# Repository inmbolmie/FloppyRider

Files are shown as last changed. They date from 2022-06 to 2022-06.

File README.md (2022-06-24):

# FloppyRider
Disk interface adapter to connect an IBM 31SD or 51TD 8-inch disk unit to a standard PC floppy controller

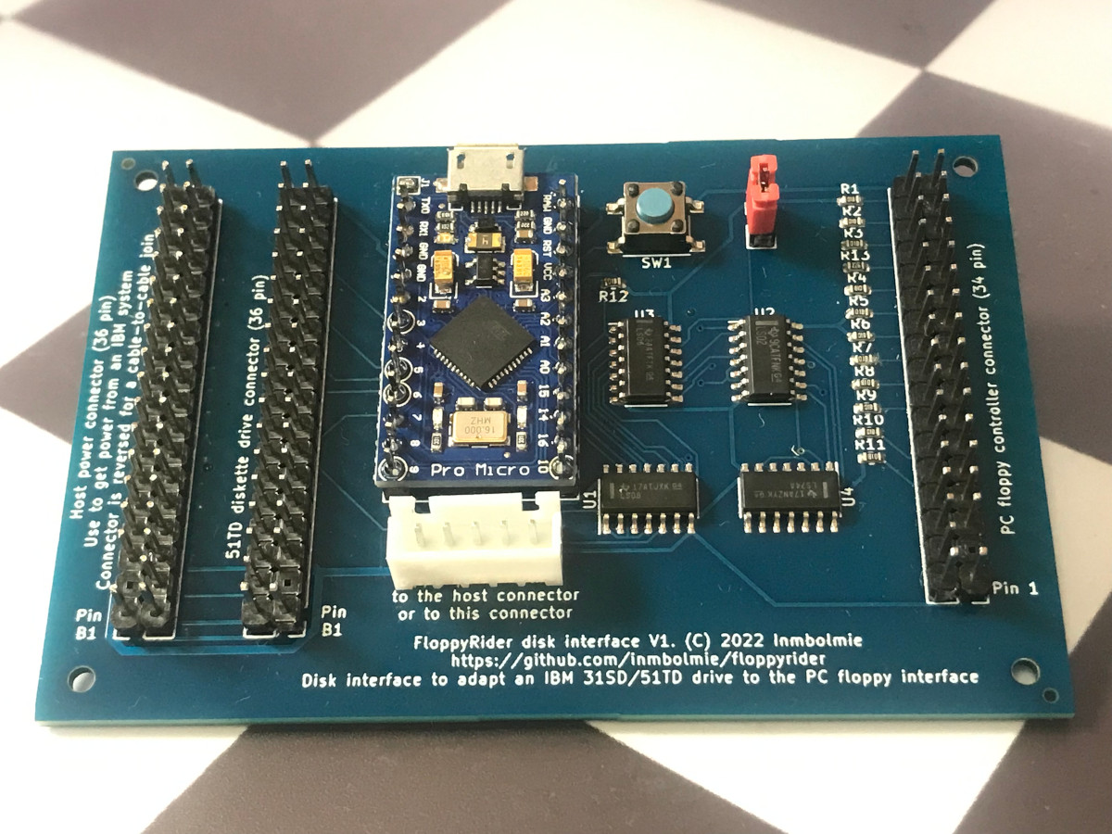
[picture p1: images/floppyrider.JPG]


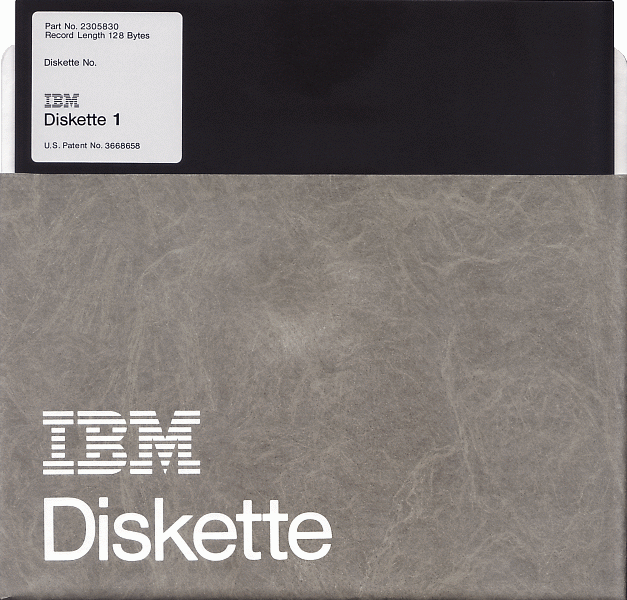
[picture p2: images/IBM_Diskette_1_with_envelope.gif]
Diskette


__This project is currently in Beta stage.__

__Second revision (20220624): I have added a transistor to drive the write/erase-gate signals on the IBM drive. I have noticed that write/erase-gate have a very low input impedance (90 ohms each, could that be a safety measure to make harder to accidentally drive the signal high?) that is way over-spec for the 74LS logic to drive properly. The prototype worked by pure luck but trying with other 74LS components the signal level was too low to enable the gates so the device was only capable of reading. The solution is to include a transistor to drive that signals up to aceptable levels.__

## Introduction

This is an ongoing project to create an adapter to be able to use IBM 8-inch Diskette drives with a standard PC floppy controller.

I currently have a working prototype capable of reading, writing and formatting Diskette 1,2 (SD) and 2D (DD) types on a 51TD disk drive. Further testing will be needed to consider it stable and fully operational.

## Videos

Video showing the adapter in action, here it is used to make an 8-inch diskette MSDOS-bootable:

[Booting MSDOS from an IBM 51TD 8-inch drive](https://www.youtube.com/watch?v=TbLUqG_d6FU)

Using the adapter to image a 33FD-formatted diskette with Imagedisk:

[Imaging on a PC an IBM 8-inch diskette with a 51TD diskette drive, Imagedisk and FloppyRider](https://www.youtube.com/watch?v=4pZ3qMAHVGs)

This project was inspired by CuriousMarc's video about data recovery from 8-inch floppies. This kind of converter is something Master Ken would have made like in five minutes using a Teensy, in case they wanted to use a genuine IBM Diskette drive in their data recovery adventure.

[Fossil Data Part 2: 8-Inch IBM Floppy Data Recovery](https://www.youtube.com/watch?v=5FVwheTVWko)

## Hardware

The adapter hardware is pretty straightforward and can be made cheapily with very low-cost components:

* Pin headers and IDC ribbon cables
* Arduino ProMicro microcontroller board (5V)
* 74LS02
* 74LS06
* 74LS08
* 74LS74
* 12x1K resistors
* 1x4,7K resistor
* NPN transistor

## Software

You can get the Arduino source code for the ProMicro in the __FloppyRider__ directory. You can program it using the regular Arduino IDE.

## KiCad Project

You can get the current project files in the __KiCad__ directory. The PCB design has not been validated at this point.

## Warning about some floppy controllers

It seems that some floppy controllers may ground the signals to the floppy drive when the computer is switched off. If you have a diskettte inserted and engaged when this happens, that can lead to the track where the head is currently positioned to be erased.

If you are working with important media be careful about this, and give power to the 51TD drive only __after__ the computer is switched on, and remove the diskette or the power to the disk drive __before__ the computer is switched off.

## Operation

These are the main points that need to be carried out for conversion:

#### Logic levels

The PC floppy signals are open collector low-level active, while the IBM signals are push-pull high-active. The 74 series chips provide most of the conversion.

All the signals are gated by the "drive select" PC signal for the adapter to be able to operate with another floppy drive on the same cable.

#### Track addressing

The PC floppy adresses tracks by a "direction" and "step" signal, and gets a "track 0" signal when the head is placed at such track. The IBM interface lacks a "track 0" signal and you control direcly the stepper motor signals "access 0" and "access 1". The ProMicro initializes the head position at track 0 at startup. From there it gets track of where the head is actually positioned and translates the required signals on both sides.

#### Write data signal.

The PC floppy write data signal generates a full pulse (falling and rising edge) for each magnetic flux transition that needs to be recorded on the disk surface, while in the IBM interface the "write data" signal records a magnetic flux transition for each signal level change (rising or falling edge). The conversion is made via the 74LS74 flip-flop.

## Connection

The 31SD and 51TD disk drives have pretty hefty power requirements, as you will need to provide them with:

* AC mains power for the disk rotating motor (on a separate connector)
* +24V at 12W (on the 36-pin idc connector)
* +5V (on the 36-pin idc connector)
* -5V (on the 36-pin idc connector)

The easier way to get all the required power rails is getting them from the original host hardware where the disk drive is enclosed. For that reason a 36-pin host connector header is provided. Note that the connector sides are mirrored to be able to use it with a cable-to-cable connection. The adapter will be placed as a bridge between the host cable and the disk drive header.

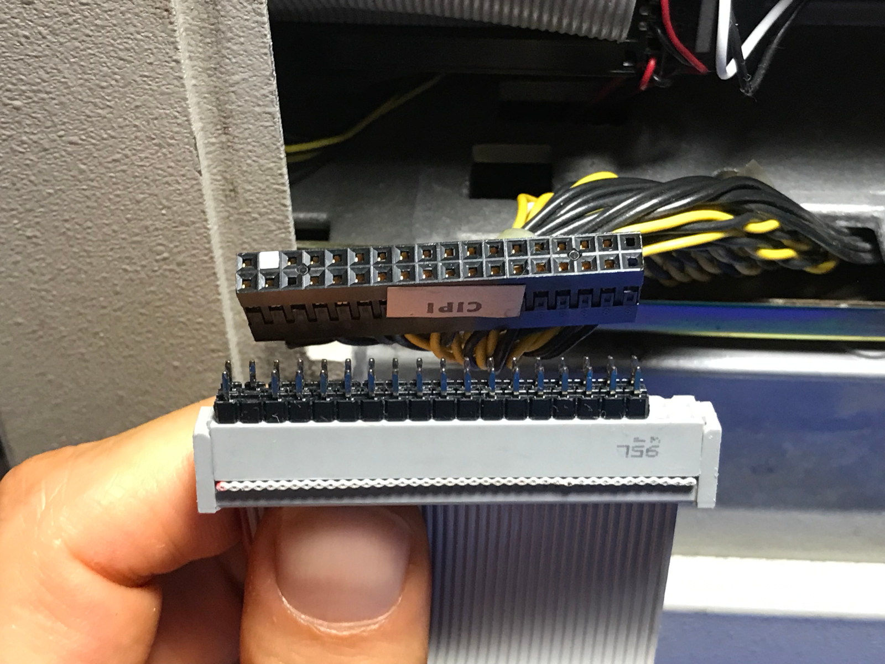
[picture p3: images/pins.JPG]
pins


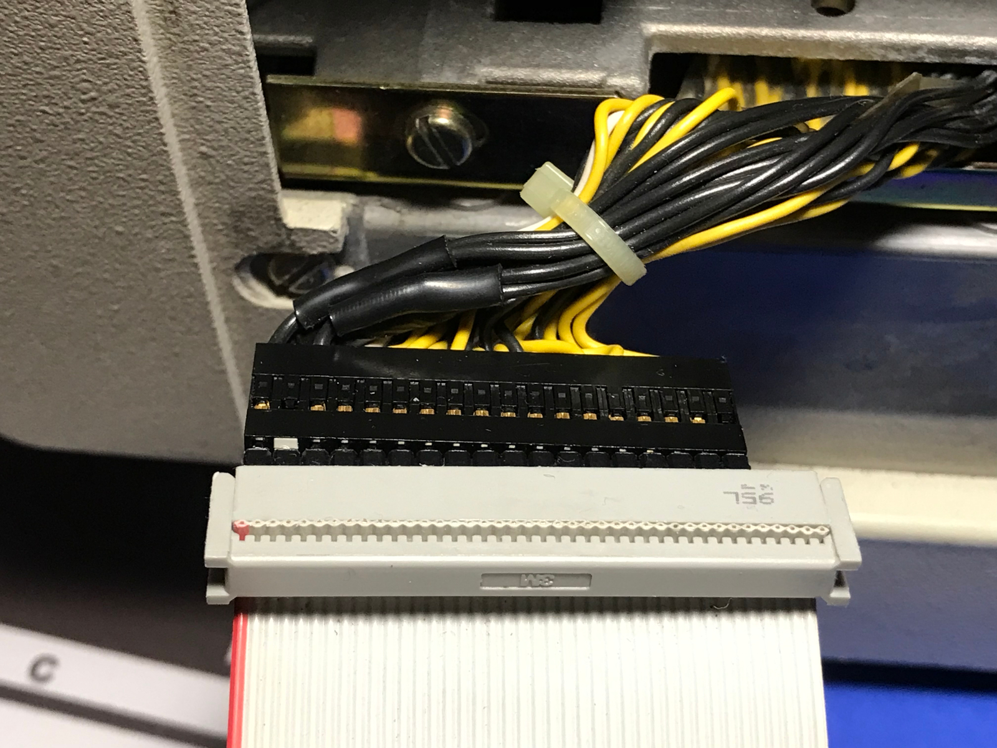
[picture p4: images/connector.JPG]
connector


If you have a separated power supply capable of providing the required DC levels you can leave the host header unconnected and provide power via a separate connector. That way something like a separated disk enclosure could be made.

The other 36-pin header will be used with a regular IDC ribbon cable connector to connect it to the disk drive. Note that you won't be _easily_ able to use the most common 40-pin cables as the available space for the connector in the disk drive is very limited.

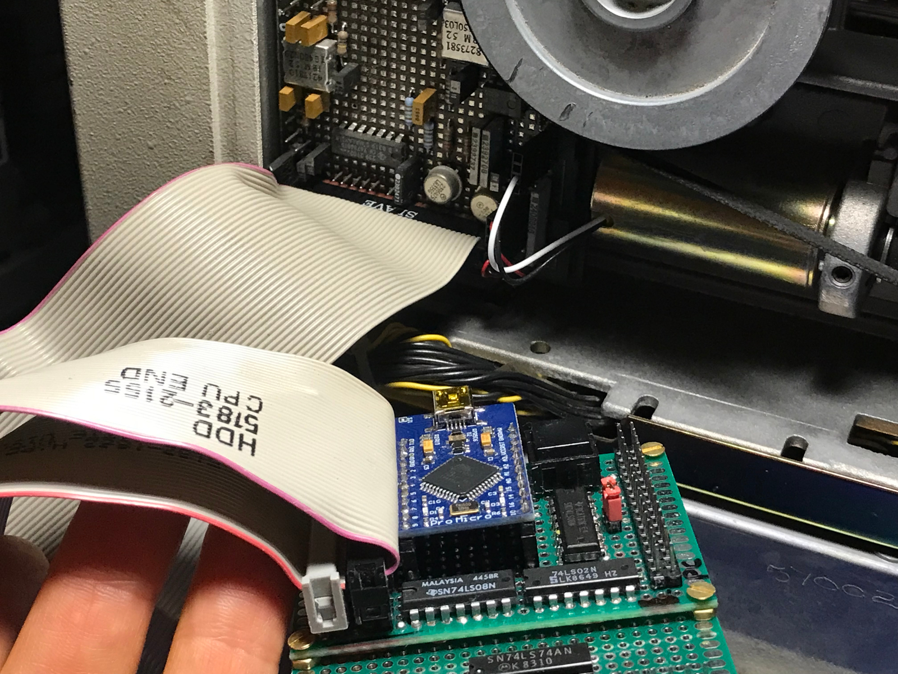
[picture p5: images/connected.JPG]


_As the connectors carry a powerful +24V signal, connector orientation is critical and getting it wrong, reversing or misplacing it could damage your hardware._

On the other end of the adapter you have a 34-pin header for the PC standard floppy cable. The adapter is hard-wired for drive B as most PC floppy drives are.

## Schematics

As currently working on the prototype unit. Subject to further modification

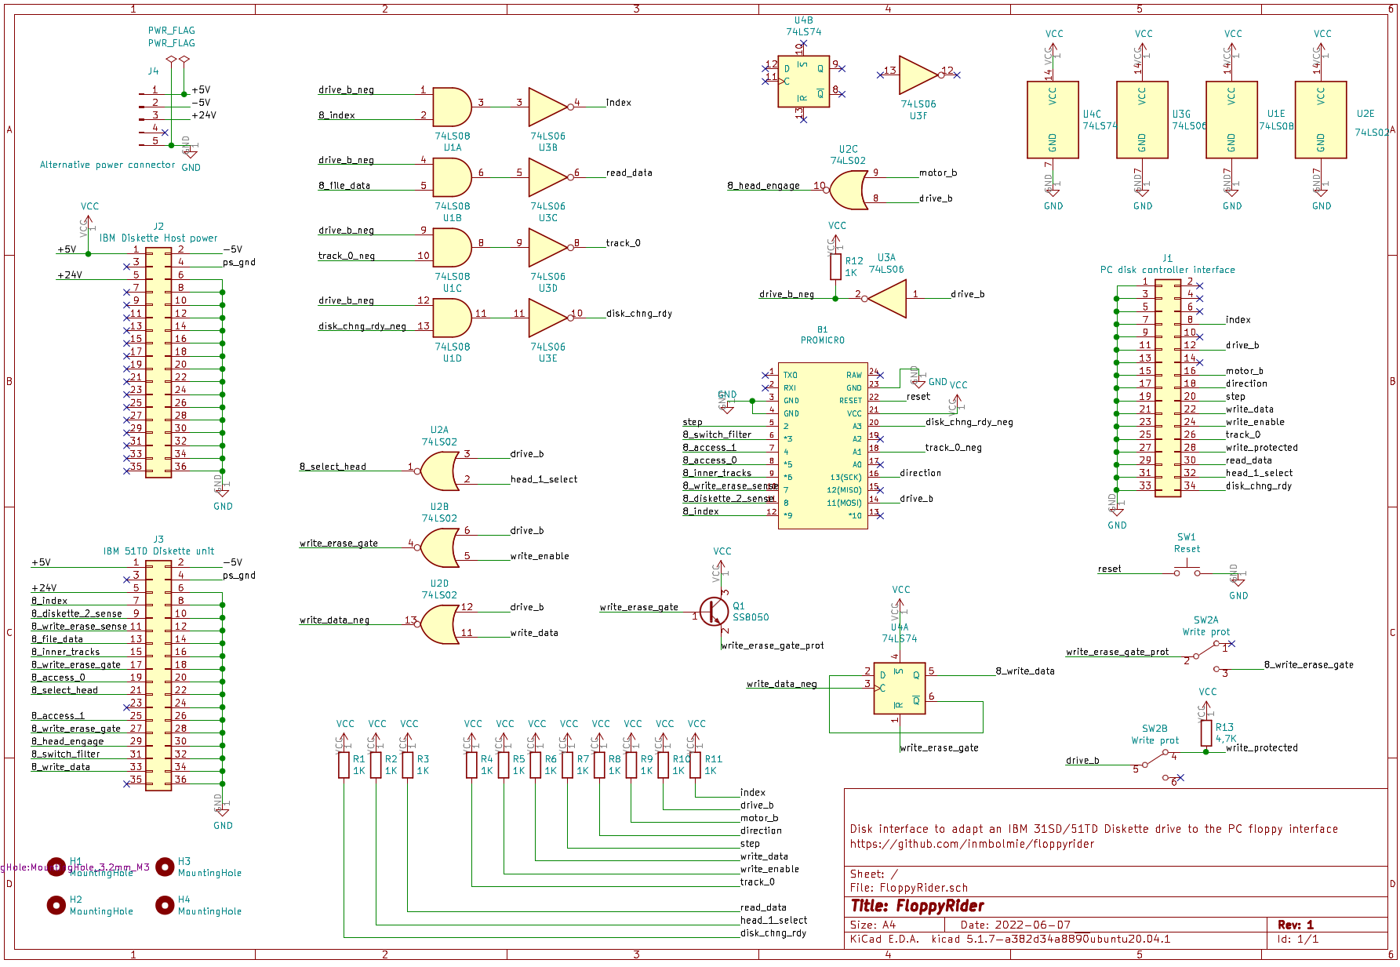
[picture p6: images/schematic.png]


## PCB

Sample of how the actual PCB could be. Not validated in production examples.

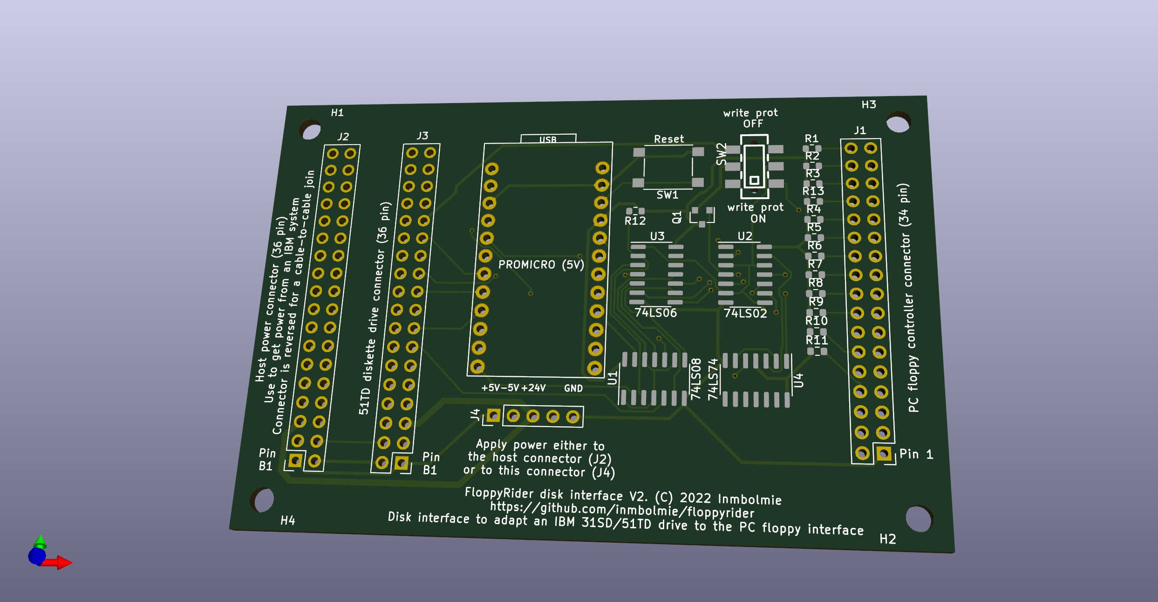
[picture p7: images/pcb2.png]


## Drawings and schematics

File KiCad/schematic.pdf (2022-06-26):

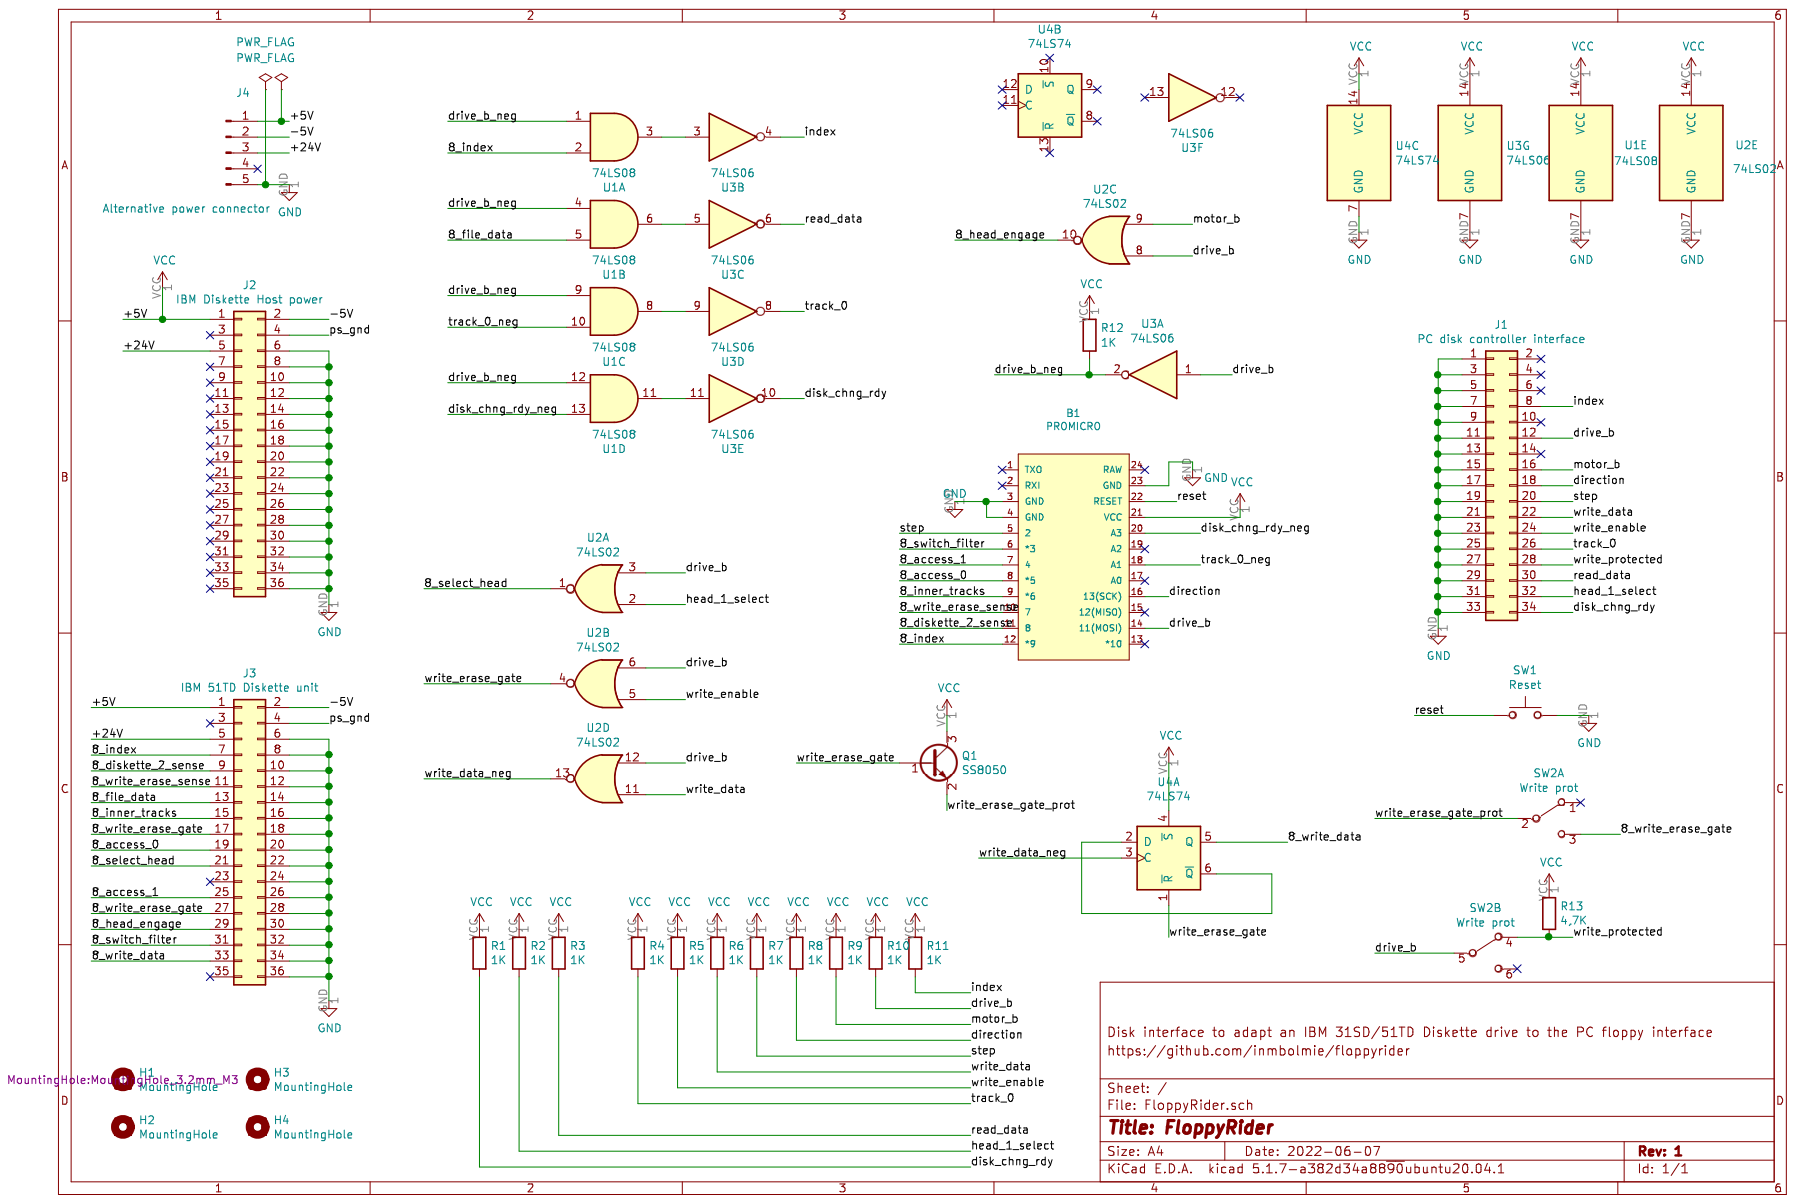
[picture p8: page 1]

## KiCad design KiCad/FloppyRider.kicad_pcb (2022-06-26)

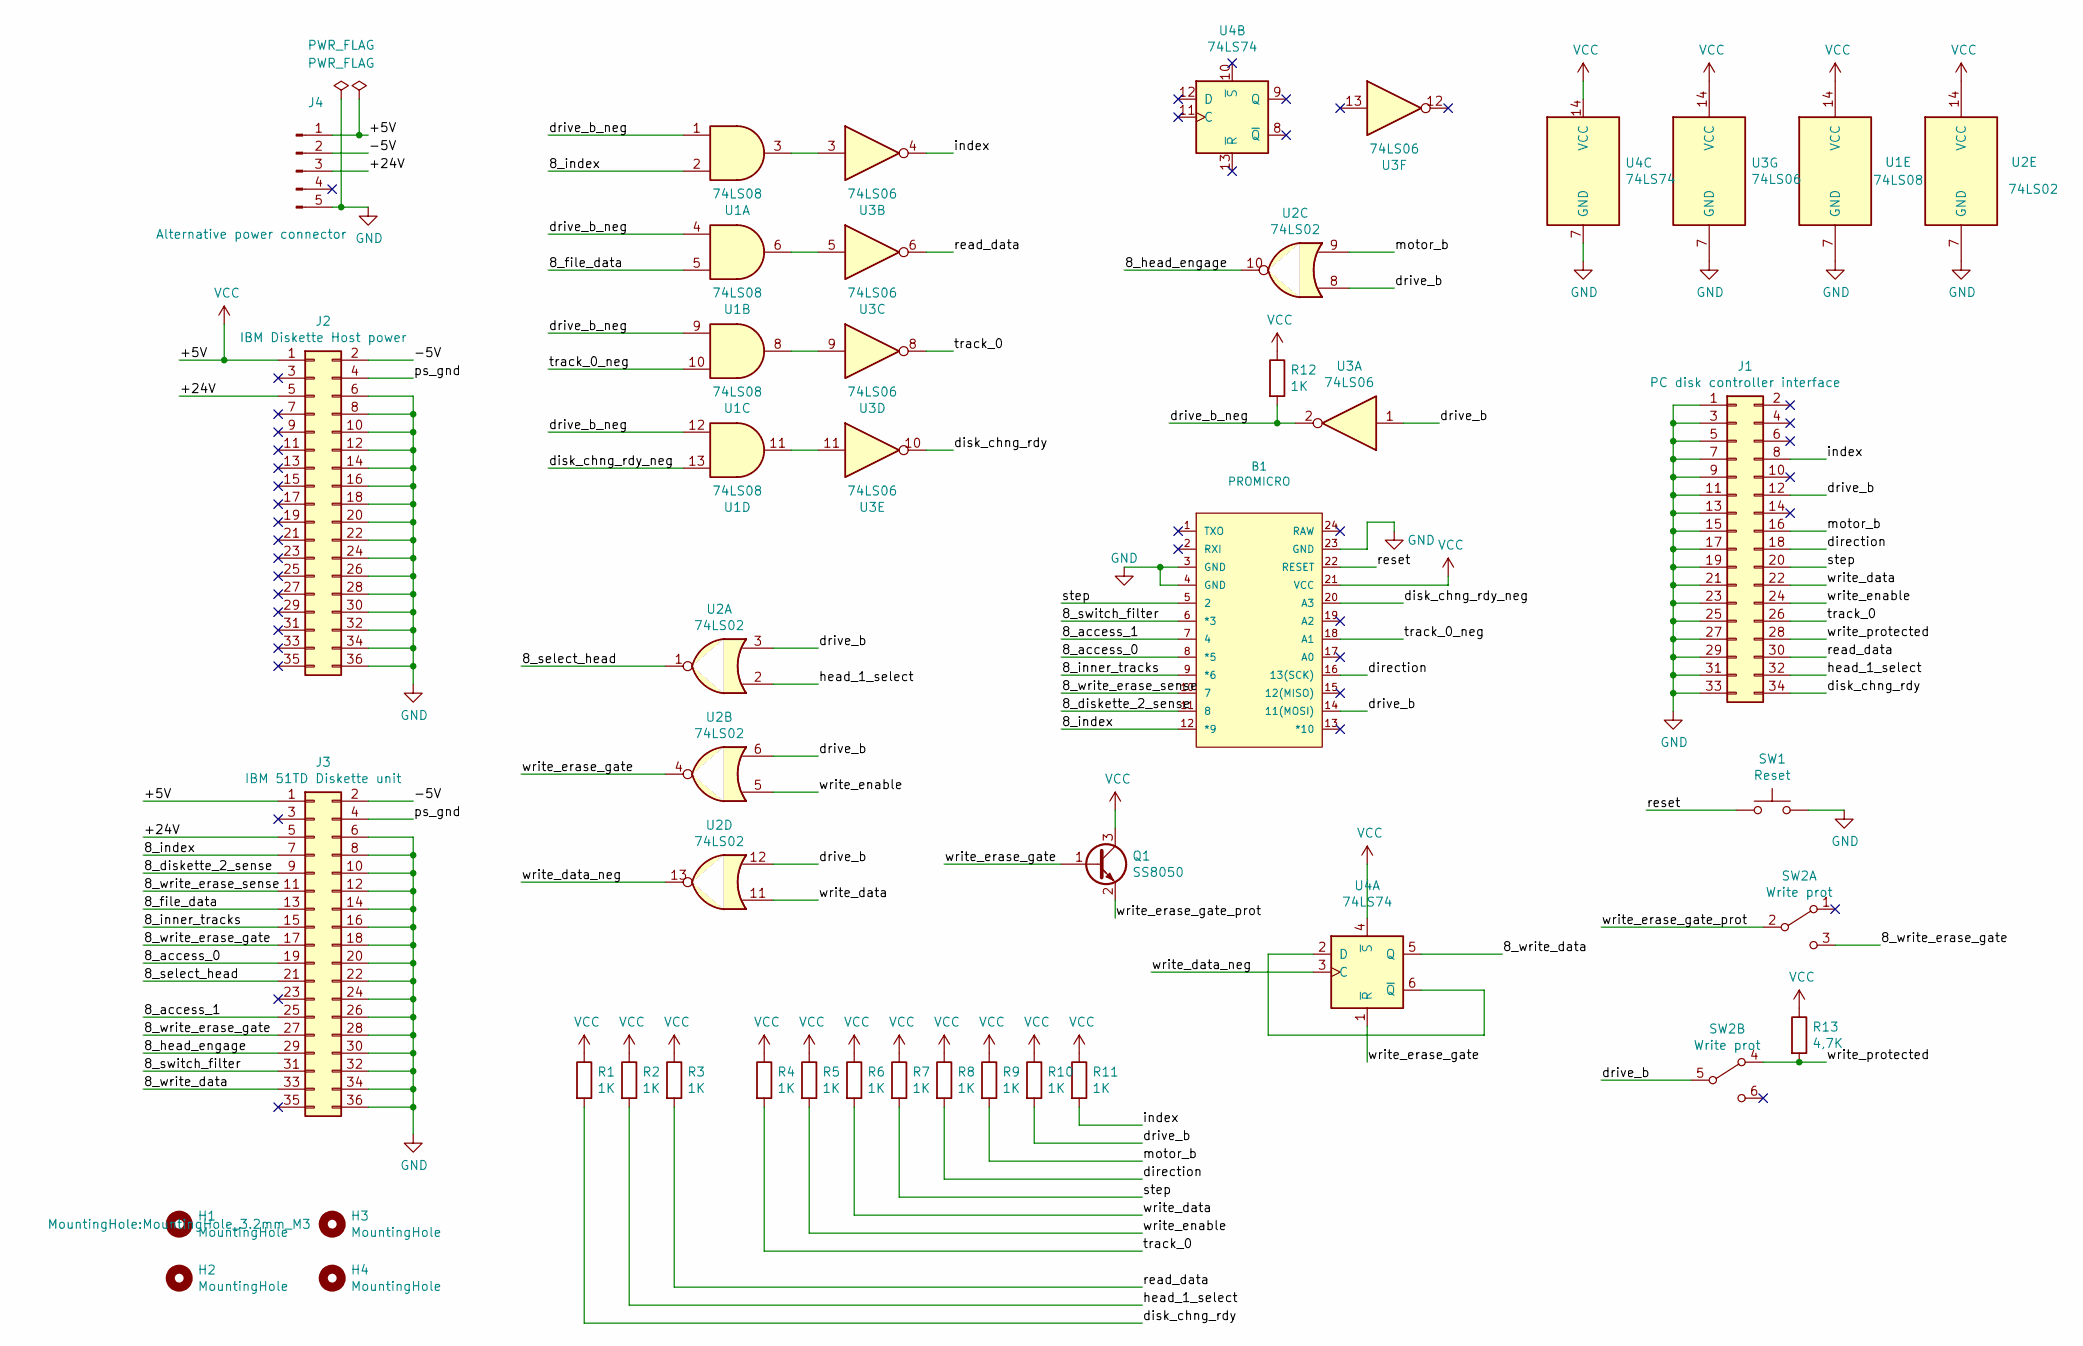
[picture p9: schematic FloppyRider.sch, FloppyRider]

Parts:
B1: PROMICRO; SPARKFUN_PRO_MICRO
H1, H2, H3, H4: MountingHole; MountingHole_3.2mm_M3
J1: PC disk controller interface; PinHeader_2x17_P2.54mm_Vertical
J2: IBM Diskette Host power; PinHeader_2x18_P2.54mm_Vertical
J3: IBM 51TD Diskette unit; PinHeader_2x18_P2.54mm_Vertical
J4: Alternative power connector; PinHeader_1x05_P2.54mm_Vertical
Q1: SS8050; SOT-23; LCSC C2150
R1, R2, R3, R4, R5, R6, R7, R8, R9, R10, R11, R12: 1K; R_0603_1608Metric; LCSC C21190
R13: 4,7K; R_0603_1608Metric; LCSC C23162
SW1: Reset; SW_Push_1P1T_NO_6x6mm_H9.5mm; LCSC C221880
SW2: Write prot; SW-TH_K3-2235S-K1
U1: 74LS08; SO-14_3.9x8.65mm_P1.27mm
U2: 74LS02; SO-14_3.9x8.65mm_P1.27mm
U3: 74LS06; SO-14_3.9x8.65mm_P1.27mm; LCSC C113682
U4: 74LS74; SO-14_3.9x8.65mm_P1.27mm; LCSC C39990

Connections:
/8_access_0: B1.8 (*5), J3.19
/8_access_1: B1.7 (4), J3.25
/8_diskette_2_sense: B1.11 (8), J3.9
/8_file_data: J3.13, U1.5
/8_head_engage: J3.29, U2.10
/8_index: B1.12 (*9), J3.7, U1.2
/8_inner_tracks: B1.9 (*6), J3.15
/8_select_head: J3.21, U2.1
/8_switch_filter: B1.6 (*3), J3.31
/8_write_data: J3.33, U4.5 (Q)
/8_write_erase_gate: J3.17, J3.27, SW2.3 (C)
/8_write_erase_sense: B1.10 (7), J3.11
/+24V: J2.5, J3.5, J4.3
/-5V: J2.2, J3.2, J4.2
/direction: B1.16 (13(SCK)), J1.18, R8.2
/disk_chng_rdy: J1.34, R1.2, U3.10
/disk_chng_rdy_neg: B1.20 (A3), U1.13
/drive_b: B1.14 (11(MOSI)), J1.12, R10.2, SW2.5 (B), U2.3, U2.6, U2.8, U2.12, U3.1
/drive_b_neg: R12.2, U1.1, U1.4, U1.9, U1.12, U3.2
/head_1_select: J1.32, R2.2, U2.2
/index: J1.8, R11.2, U3.4
/motor_b: J1.16, R9.2, U2.9
/ps_gnd: J2.4, J3.4
/read_data: J1.30, R3.2, U3.6
/reset: B1.22 (RESET), SW1.1
/step: B1.5 (2), J1.20, R7.2
/track_0: J1.26, R4.2, U3.8
/track_0_neg: B1.18 (A1), U1.10
/write_data: J1.22, R6.2, U2.11
/write_data_neg: U2.13, U4.3 (C)
/write_enable: J1.24, R5.2, U2.5
/write_erase_gate: Q1.1 (B), U2.4, U4.1 (~R)
/write_erase_gate_prot: Q1.2 (E), SW2.2 (B)
/write_protected: J1.28, R13.2, SW2.4 (A)
GND: B1.3 (GND), B1.4 (GND), B1.23 (GND), J1.1, J1.3, J1.5, J1.7, J1.9, J1.11, J1.13, J1.15, J1.17, J1.19, J1.21, J1.23, J1.25, J1.27, J1.29, J1.31, J1.33, J2.6, J2.8, J2.10, J2.12, J2.14, J2.16, J2.18, J2.20, J2.22, J2.24, J2.26, J2.28, J2.30, J2.32, J2.34, J2.36, J3.6, J3.8, J3.10, J3.12, J3.14, J3.16, J3.18, J3.20, J3.22, J3.24, J3.26, J3.28, J3.30, J3.32, J3.34, J3.36, J4.5, SW1.2, U1.7 (GND), U2.7 (GND), U3.7 (GND), U4.7 (GND)
unnamed: U1.3, U3.3
unnamed: U1.6, U3.5
unnamed: U1.8, U3.9
unnamed: U1.11, U3.11
unnamed: U4.2 (D), U4.6 (~Q)
VCC: B1.21 (VCC), J2.1, J3.1, J4.1, Q1.3 (C), R1.1, R2.1, R3.1, R4.1, R5.1, R6.1, R7.1, R8.1, R9.1, R10.1, R11.1, R12.1, R13.1, U1.14 (VCC), U2.14 (VCC), U3.14 (VCC), U4.4 (~S), U4.14 (VCC)

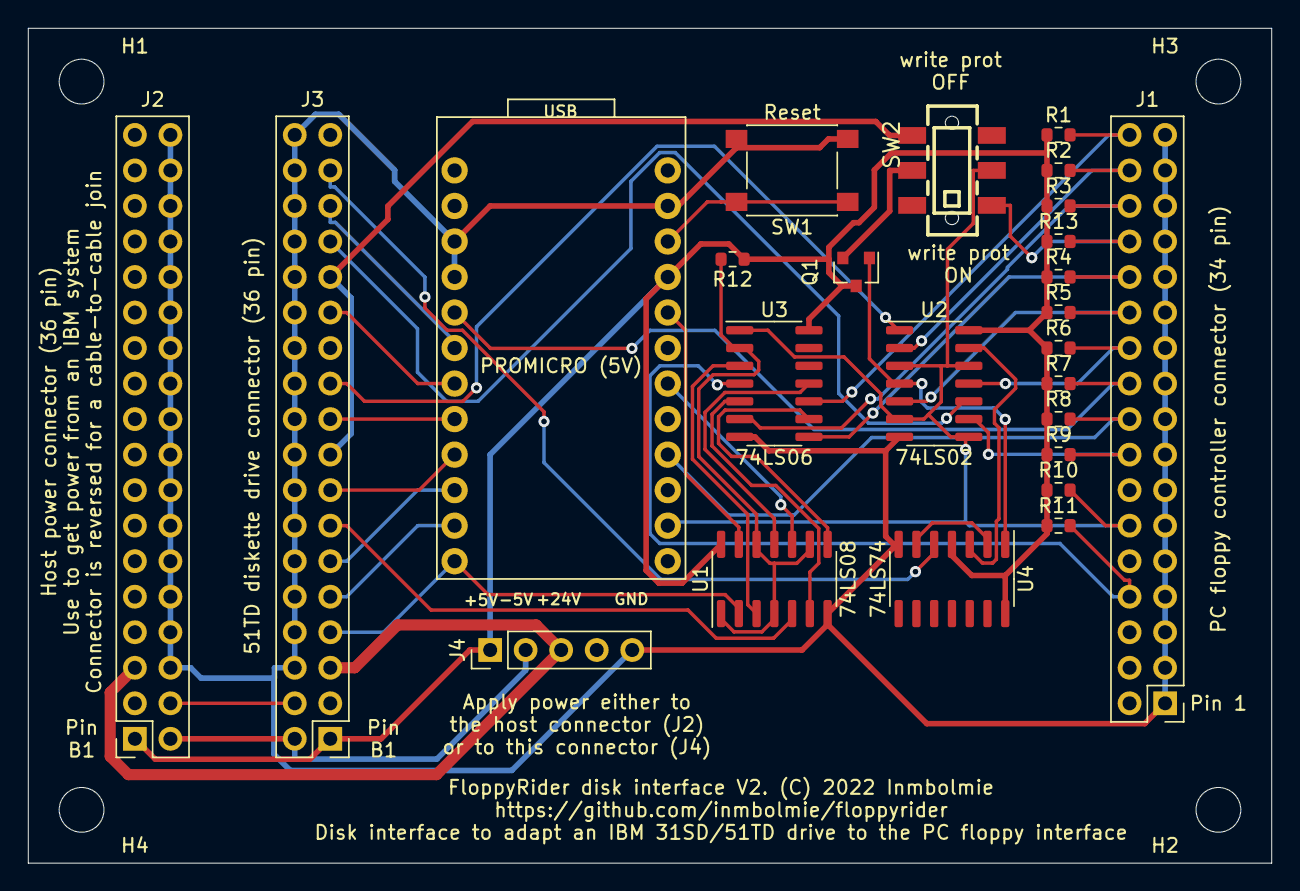
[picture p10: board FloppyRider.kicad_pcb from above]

Board: 2 copper layers, 88.9 x 59.7 mm, 29 parts (0 on the bottom side), 41 nets.

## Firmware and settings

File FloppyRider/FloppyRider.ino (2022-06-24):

/*
   FloppyRider diskette controller
   Arduino microcontroller firmware
   (C) 2022 Inmbolmie

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
   You should have received a copy of the GNU General Public License
   along with this program.  If not, see <https://www.gnu.org/licenses/>.
*/

#include <Arduino.h>

const boolean debug = true;

//Input ports from 51TD
const int PIN_IN_INDEX = 9;
const int PIN_IN_DISKETTE_2_SENSE = 8;
const int PIN_IN_WRITE_ERASE_SENSE = 7;

//Input ports from PC
const int PIN_IN_STEP = 2;
const int PIN_IN_DIRECTION_AWAY = 15;
const int PIN_IN_DRIVE_SELECT_A = 16;


//Output ports to 51TD
const int PIN_OUT_SWITCH_FILTER = 3;
const int PIN_OUT_ACCESS_1 = 4;
const int PIN_OUT_ACCESS_0 = 5;
const int PIN_OUT_INNER_TRACKS = 6;

//Output ports to PC
const int PIN_OUT_DSK_CHNG_RDY_NEG = A3;
const int PIN_OUT_TRACK_0_NEG = A1;

//8-inch drive number of tracks
const int maxTrack = 76;

//Controller state
int currentTrack = 80;
int desiredTrack = 80;
boolean access0 = true;
boolean access1 = true;
boolean stepReceived = false;

void setup() {

  if (debug) Serial.begin(9600);

  //push-pull outputs to 51TD
  pinMode(3, OUTPUT);
  pinMode(4, OUTPUT);
  pinMode(5, OUTPUT);
  pinMode(6, OUTPUT);

  //open-collector (through 74LS06) outputs to pc
  pinMode(A1, OUTPUT);
  pinMode(A3, OUTPUT);

  //inputs from pc
  pinMode(2, INPUT);
  pinMode(15, INPUT_PULLUP);
  pinMode(16, INPUT);

  //inputs from 51TD
  pinMode(9, INPUT);
  pinMode(8, INPUT);
  pinMode(7, INPUT);

  //not used
  pinMode(0, INPUT);
  pinMode(1, INPUT);
  pinMode(10, INPUT);
  pinMode(14, INPUT);
  pinMode(A0, INPUT);
  pinMode(A2, INPUT);


  //initialize outputs
  digitalWrite (PIN_OUT_SWITCH_FILTER, LOW) ;
  digitalWrite (PIN_OUT_ACCESS_1, HIGH) ;
  digitalWrite (PIN_OUT_ACCESS_0, HIGH) ;
  digitalWrite (PIN_OUT_INNER_TRACKS, LOW) ;

  digitalWrite (PIN_OUT_DSK_CHNG_RDY_NEG, LOW) ;
  digitalWrite (PIN_OUT_TRACK_0_NEG, LOW) ;

  delay (1000);

  //Move head to track0 to start from known position
  while (currentTrack > 0) {
    move_head_in();
    desiredTrack--;
    currentTrack--;
  }

  //Signal /track 0 to PC
  out_to_high(PIN_OUT_TRACK_0_NEG);

  //Interrupt when step received (falling edge)
  attachInterrupt(digitalPinToInterrupt(PIN_IN_STEP), step_received, FALLING);


}

void loop() {
  if (currentTrack != desiredTrack) {

    if (desiredTrack < currentTrack) {
      if (currentTrack < 77)
      {
        move_head_in();
      }
      currentTrack--;

    } else {
      if (currentTrack < 76)
      {
        move_head_out();
      }
      currentTrack++;
    }

    if (currentTrack == 0) {
      //Enable /track0 signal
      out_to_high(PIN_OUT_TRACK_0_NEG);
    } else {

      if (currentTrack >= 43) {
        //Enable inner tracks signal
        out_to_high(PIN_OUT_INNER_TRACKS);
      } else {
        //Disable inner tracks signal
        out_to_low(PIN_OUT_INNER_TRACKS);
      }

      if (currentTrack >= 60) {
        //Enable switch filter signal if diskette2 is detected
        if (digitalRead(PIN_IN_DISKETTE_2_SENSE)) {
          out_to_high(PIN_OUT_SWITCH_FILTER);
        }
      } else {
        //Disable switch filter signal
        out_to_low(PIN_OUT_SWITCH_FILTER);
      }

      //Disable /track0 signal
      out_to_low(PIN_OUT_TRACK_0_NEG);
    }

    if (debug) Serial.print("New track: ");
    if (debug) Serial.println(currentTrack, DEC);

    digitalWrite(LED_BUILTIN_RX, !digitalRead(LED_BUILTIN_RX));
  }

}


void out_to_low(int pin) {
  digitalWrite(pin, false);
}



void out_to_high(int pin) {
  digitalWrite(pin, true);
}



void move_head_in() {
  if (access0 && access1) {
    access1 = false;
    out_to_low(PIN_OUT_ACCESS_1);
  } else if (!access0 && access1) {
    access0 = true;
    out_to_high(PIN_OUT_ACCESS_0 );
  } else if (!access0 && !access1) {
    access1 = true;
    out_to_high(PIN_OUT_ACCESS_1);
  } else if (access0 && !access1) {
    access0 = false;
    out_to_low(PIN_OUT_ACCESS_0);
  }
  delay(5);
}


void move_head_out() {
  if (access0 && access1) {
    access0 = false;
    out_to_low(PIN_OUT_ACCESS_0);
  } else if (!access0 && access1) {
    access1 = false;
    out_to_low(PIN_OUT_ACCESS_1);
  } else if (!access0 && !access1) {
    access0 = true;
    out_to_high(PIN_OUT_ACCESS_0);
  } else if (access0 && !access1) {
    access1 = true;
    out_to_high(PIN_OUT_ACCESS_1);
  }
  delay(5);

}

void step_received() {
  boolean direction_away = !digitalRead(PIN_IN_DIRECTION_AWAY);
  //Check if disk is selected (pcb is hardcoded to drive B as standard for PC floppies  
  boolean disk_selected = !digitalRead(PIN_IN_DRIVE_SELECT_A);

  if (!disk_selected) {
    return;
  }

  
  if (direction_away && desiredTrack < 79) {
    desiredTrack++;
  } else if (!direction_away && desiredTrack > 0) {
    desiredTrack--;
  }



}

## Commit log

2022-06-10 Changes for initial release
    [FloppyRider.kicad_pcb, FloppyRider.sch]
2022-06-24 Added transistor to drive write/erase gate signals
    [FloppyRider.kicad_pcb, FloppyRider.sch]
2022-06-24 Improved fast track changes
2022-06-26 Added hard write protection switch
    [FloppyRider.kicad_pcb, FloppyRider.sch]

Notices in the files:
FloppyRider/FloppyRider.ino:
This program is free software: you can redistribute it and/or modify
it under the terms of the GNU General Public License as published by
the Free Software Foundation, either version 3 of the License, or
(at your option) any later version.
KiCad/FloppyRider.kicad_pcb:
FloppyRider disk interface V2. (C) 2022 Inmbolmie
